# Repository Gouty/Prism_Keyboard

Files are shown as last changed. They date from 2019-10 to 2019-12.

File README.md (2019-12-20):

# Prism Pixel Art Prism Mechanical Keyboard

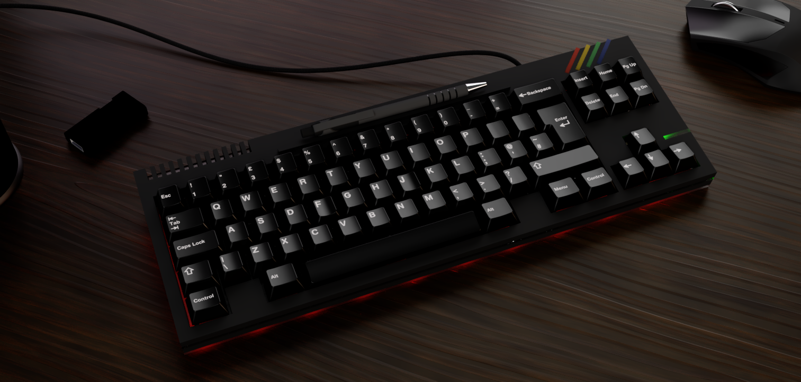
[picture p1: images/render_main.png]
Render


Prism is a low cost QMK compatable 60% + nav cluster (or TKL minus F-row if you prefer) keyboard.

It came about for a number of reasons:

 * I had some [TGW71 PCBs](https://www.reddit.com/r/MechanicalKeyboards/comments/5un33s/the_great_wave_custom_board/) designed by [u/ca178858](https://www.reddit.com/user/ca178858) lying around doing nothing
 * I am procrastinating instead of doing my PhD thesis writeup
 * There was a competition on [r/CustomKeyboards](https://www.reddit.com/r/CustomKeyboards/) to build retro themed keyboards.

As it was planned for the OG Summer competition I decided to emulate some of the design language of the [ZX Sepctrum](https://imgur.com/a/drfZssH) family of computers (particularly the the ones that came after the 48k).

## Initial Design document

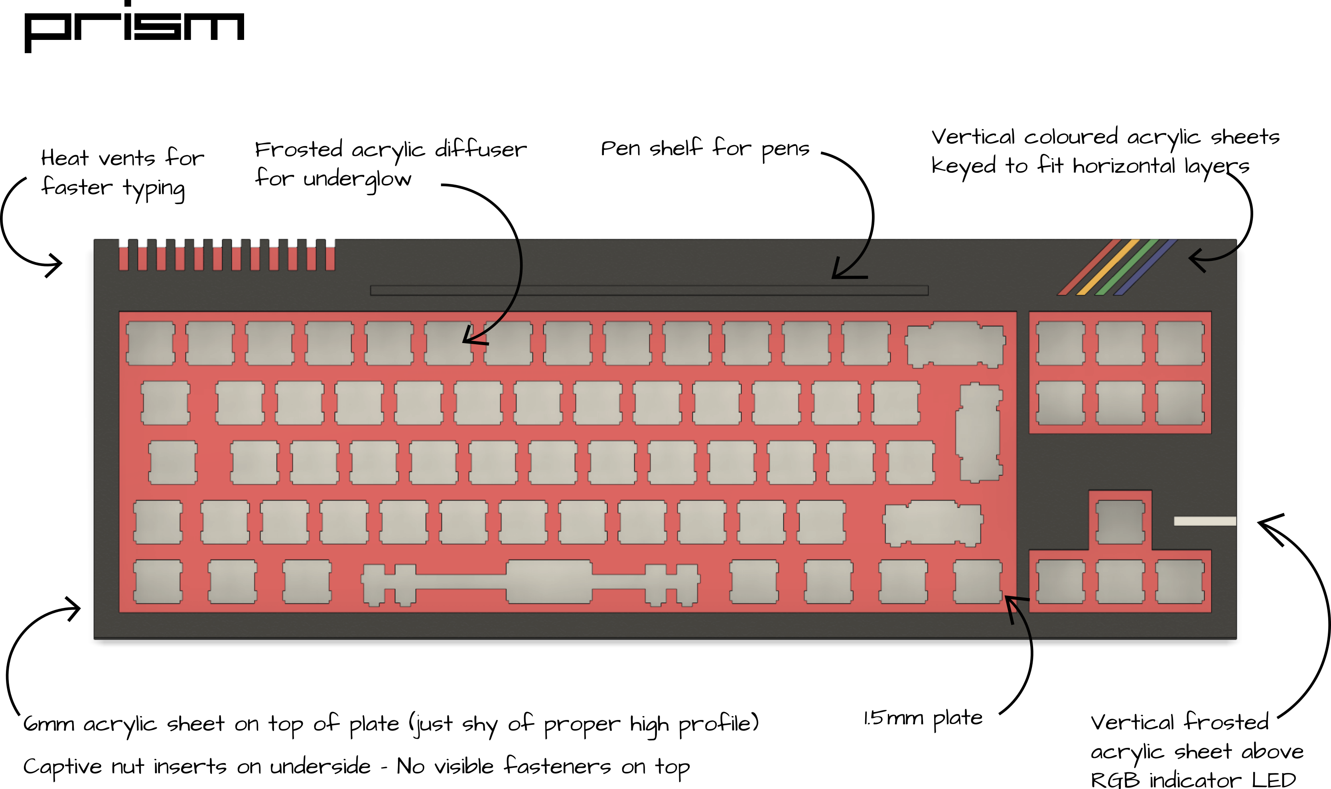
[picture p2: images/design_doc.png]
Design Doc
 explode

## To Do

* Improve feet fastening/height adjustment
* Update .dxf to include latest revision

## Future Plans

Currently this repo is a bit of a dumping ground for what I have designed so far, though it is possible to recreate the keyboard entirely. Eventually I want it to include:

* Multiple plate layer configurations
* Multiple top layer configuations
* Changes to the PCB to include PCB mount stabilisers and better bottom row support

## Current status

Prototype complete - Displayed at Mechanical Keyboard Meetup (Leeds 26/10/2019)

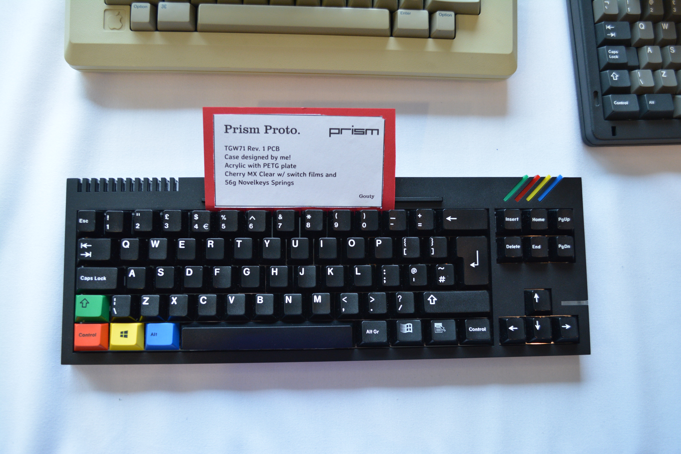
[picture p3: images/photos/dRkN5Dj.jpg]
MKUK Leeds


## Posts about Prism

* [Initial](https://www.reddit.com/r/CustomKeyboards/comments/c7dlp8/ogsummer_zx_spectrum_inspired_work_in_progress/)
* [Update](https://www.reddit.com/r/CustomKeyboards/comments/cu45r6/ogsummer_prism_zx_spectrum_inspired_update/)
* [Keebtalk](https://www.keebtalk.com/t/prism-a-zx-spectrum-inspired-low-cost-acrylic-case/)
* [Prototype](https://www.reddit.com/r/MechanicalKeyboards/comments/dqqovr/rbgy/), [2](https://www.reddit.com/r/CustomKeyboards/comments/dqr5ce/prism_prototype/)

## Thanks

Original TGW71 PCB by [u/ca178858](https://www.reddit.com/user/ca178858) and [u/the_pokemon_kid](https://www.reddit.com/user/the_pokemon_kid)

Pixel art by Meowsaur

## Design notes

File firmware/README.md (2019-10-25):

Trying to get buildfiles (if I don't get them I'll try and make my own) but in the meantime

.json works in [Keyboard Firmware Builder](https://kbfirmware.com/) but RGB doesn't work for some reason.

.hex currently uploaded works with basic layout and working RGB

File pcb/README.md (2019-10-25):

# TGW71 PCB

Original files kindly provided by [u/ca178858](https://www.reddit.com/user/ca178858)

BOM:

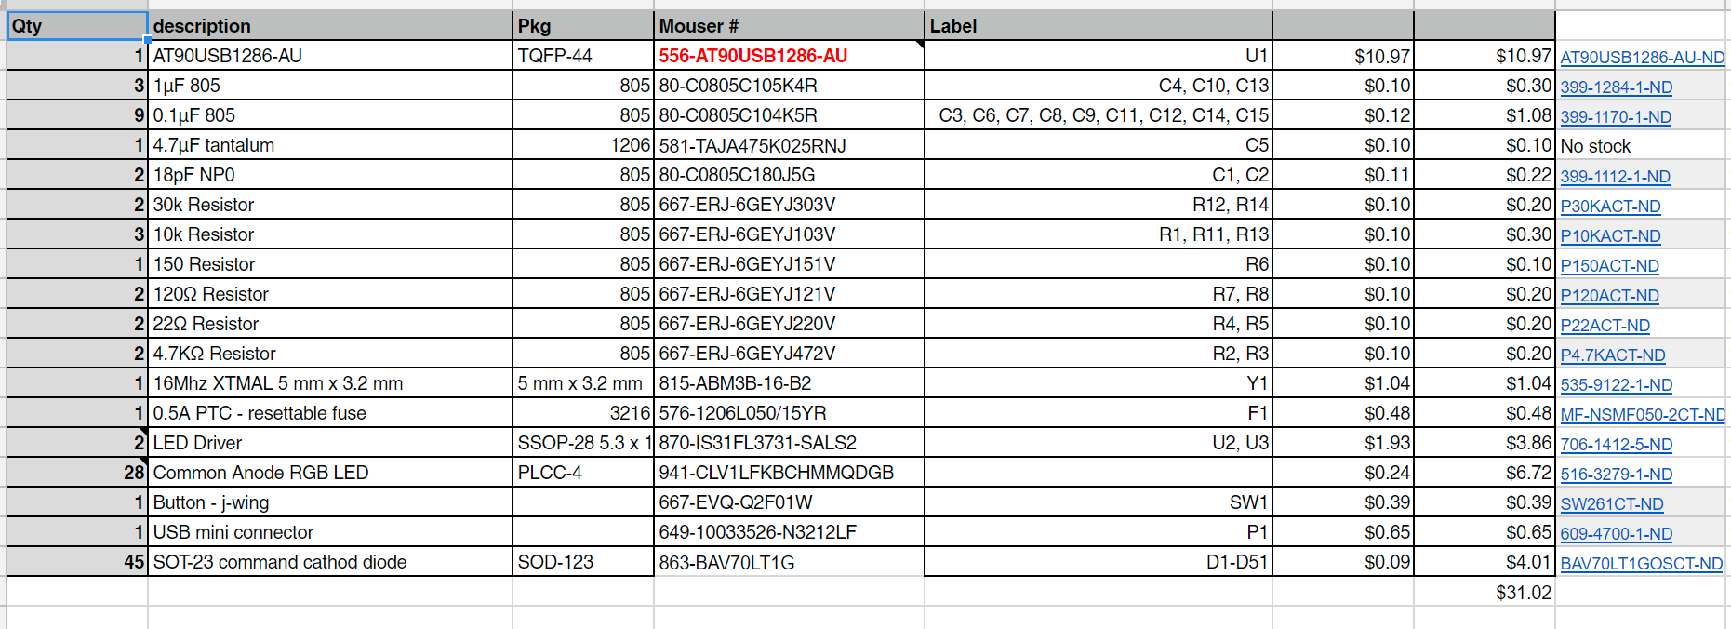
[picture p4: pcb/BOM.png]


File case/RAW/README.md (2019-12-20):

##Raw DXF files

The are the files organised into individual components.

They have no kerf applied to them, but slotted components do have additional small amount of clearance around them (0.15mm to 0.25mm)

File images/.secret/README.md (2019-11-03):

# Super Secret Cheeki Breeki Edition

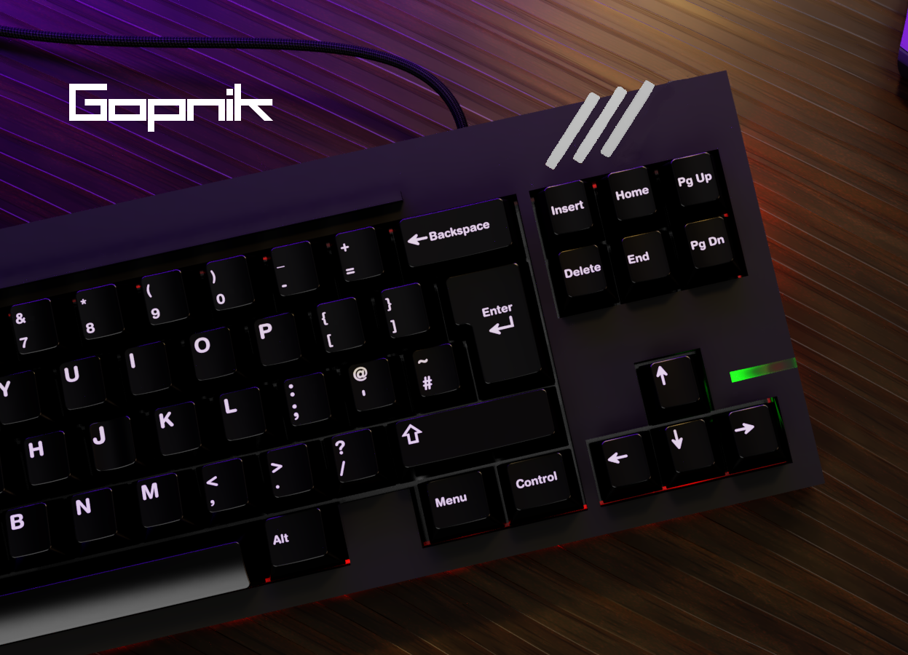
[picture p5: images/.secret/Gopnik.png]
Gopnik


No feet, flat squat on table just as mother ~~russia~~ nature intend.

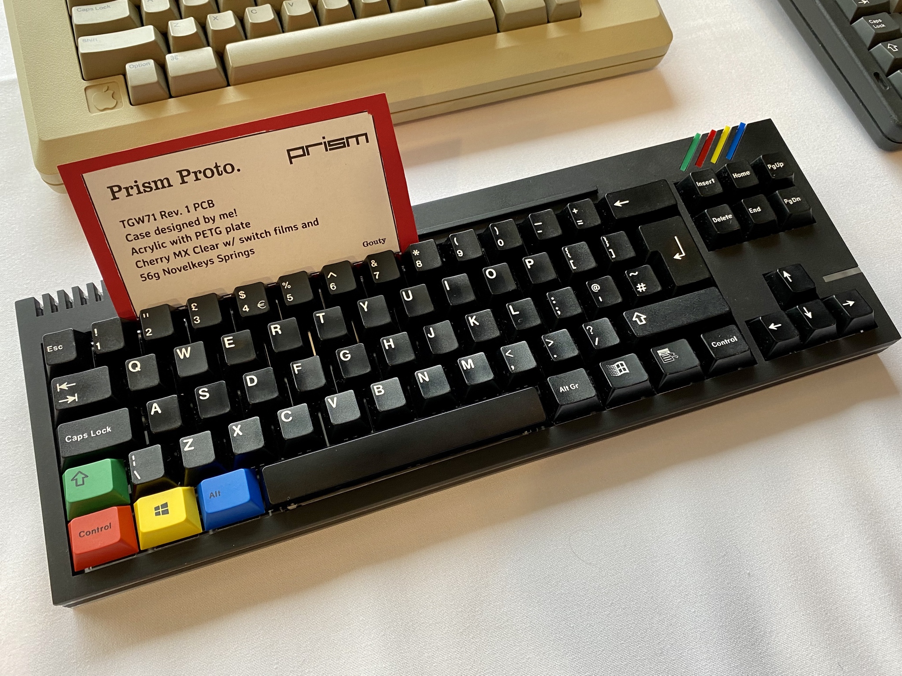
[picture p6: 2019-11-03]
images/photos/1HwlqcJ.jpg

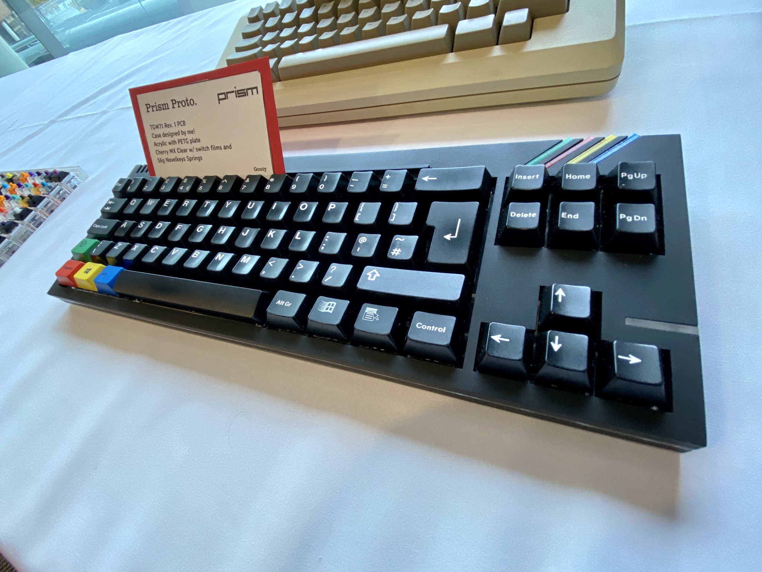
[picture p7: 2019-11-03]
images/photos/UL6nE1i.jpg

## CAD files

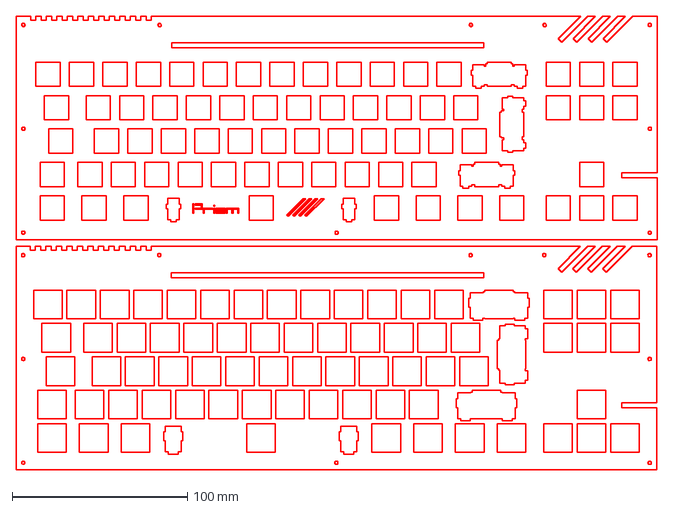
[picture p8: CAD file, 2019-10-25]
case/By material/Clear PETG 1_5mm.dxf
365.4 x 258.7 mm

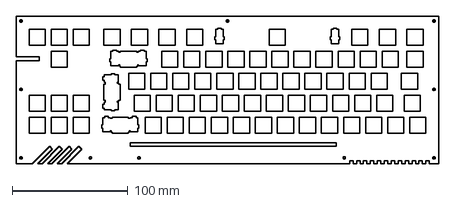
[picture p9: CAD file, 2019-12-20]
case/RAW/Plate(ISO).dxf
365.1 x 127.4 mm

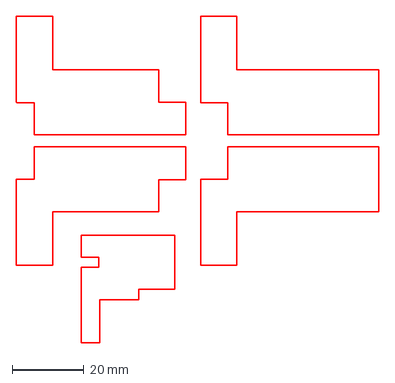
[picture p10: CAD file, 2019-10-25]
case/By material/Colours 3mm.dxf
101.2 x 91.3 mm

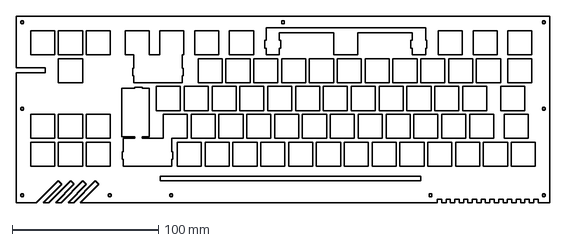
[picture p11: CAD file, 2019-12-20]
case/RAW/Underplate(ISO).dxf
365.1 x 127.4 mm

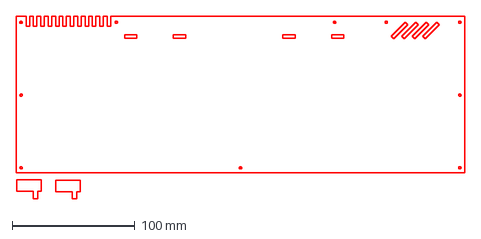
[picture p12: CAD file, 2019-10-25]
case/By material/Frosted Clear 3mm.dxf
365.3 x 148.7 mm

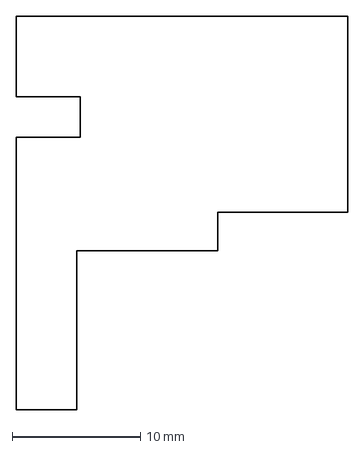
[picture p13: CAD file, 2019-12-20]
case/RAW/Colour Stripe.dxf
25.9 x 30.7 mm

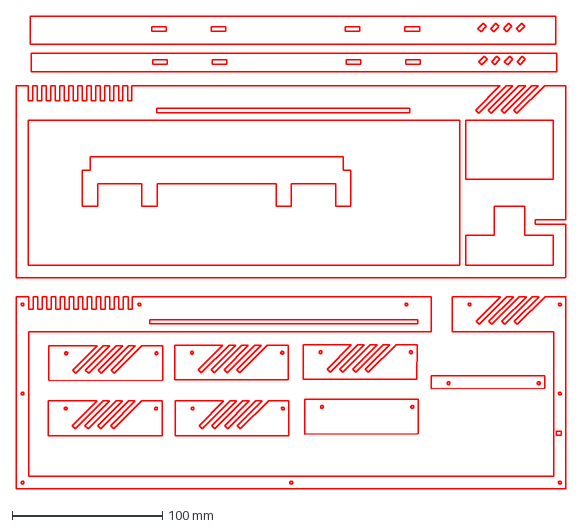
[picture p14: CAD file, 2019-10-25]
case/By material/Black 6mm.dxf
365.6 x 314.1 mm

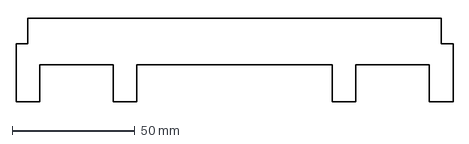
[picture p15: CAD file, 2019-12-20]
case/RAW/Pen holder.dxf
177.9 x 34.2 mm

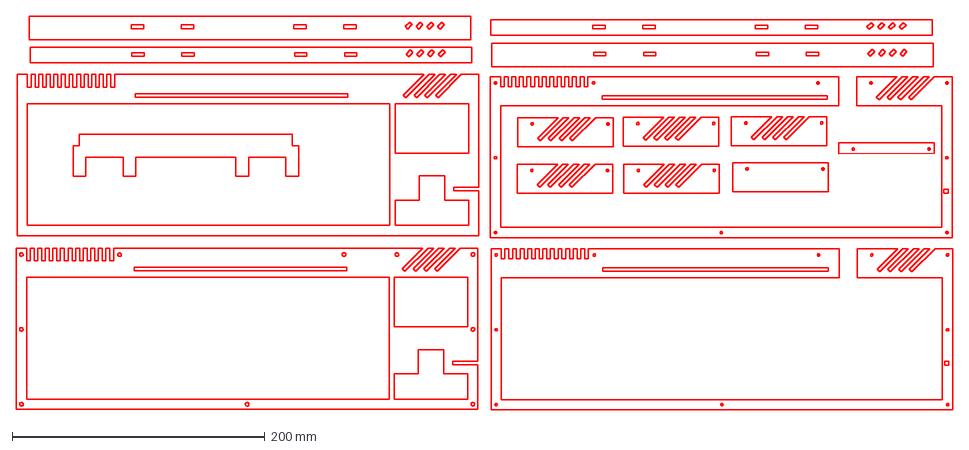
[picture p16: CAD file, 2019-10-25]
case/By material/Black 3mm.dxf
740.9 x 311.4 mm

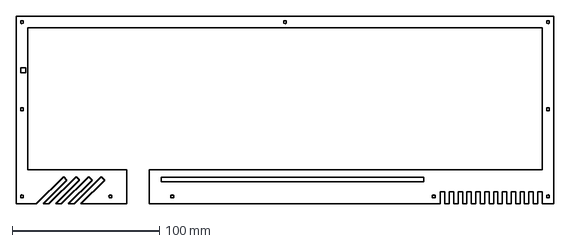
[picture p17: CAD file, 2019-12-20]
case/RAW/Mid.dxf
365.1 x 127.4 mm

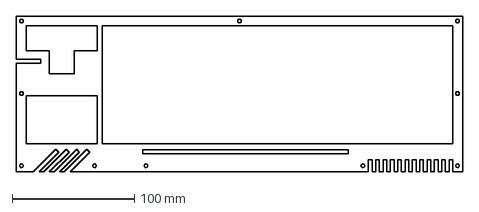
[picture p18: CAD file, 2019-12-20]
case/RAW/Top under.dxf
365.1 x 127.4 mm

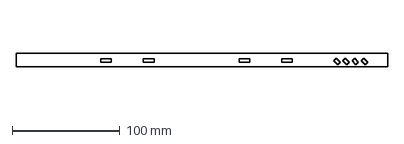
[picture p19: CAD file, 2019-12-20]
case/RAW/Bottom foot.dxf
345.1 x 12.3 mm

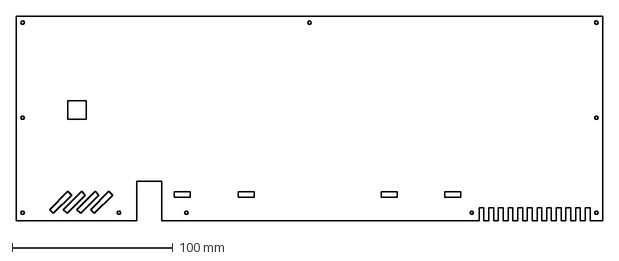
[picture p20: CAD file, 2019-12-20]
case/RAW/Base.dxf
365.1 x 127.4 mm

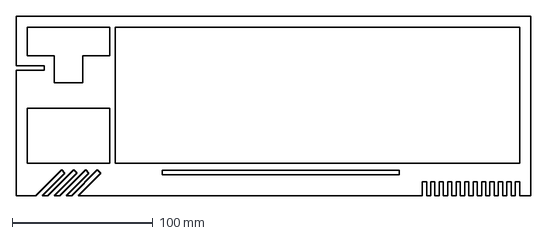
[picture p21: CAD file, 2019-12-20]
case/RAW/Top.dxf
365.1 x 127.4 mm

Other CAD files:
case/RAW/Colour Holder outer.dxf
case/RAW/Colour Holder inner.dxf
case/RAW/Top foot.dxf
case/RAW/Light Pipe.dxf

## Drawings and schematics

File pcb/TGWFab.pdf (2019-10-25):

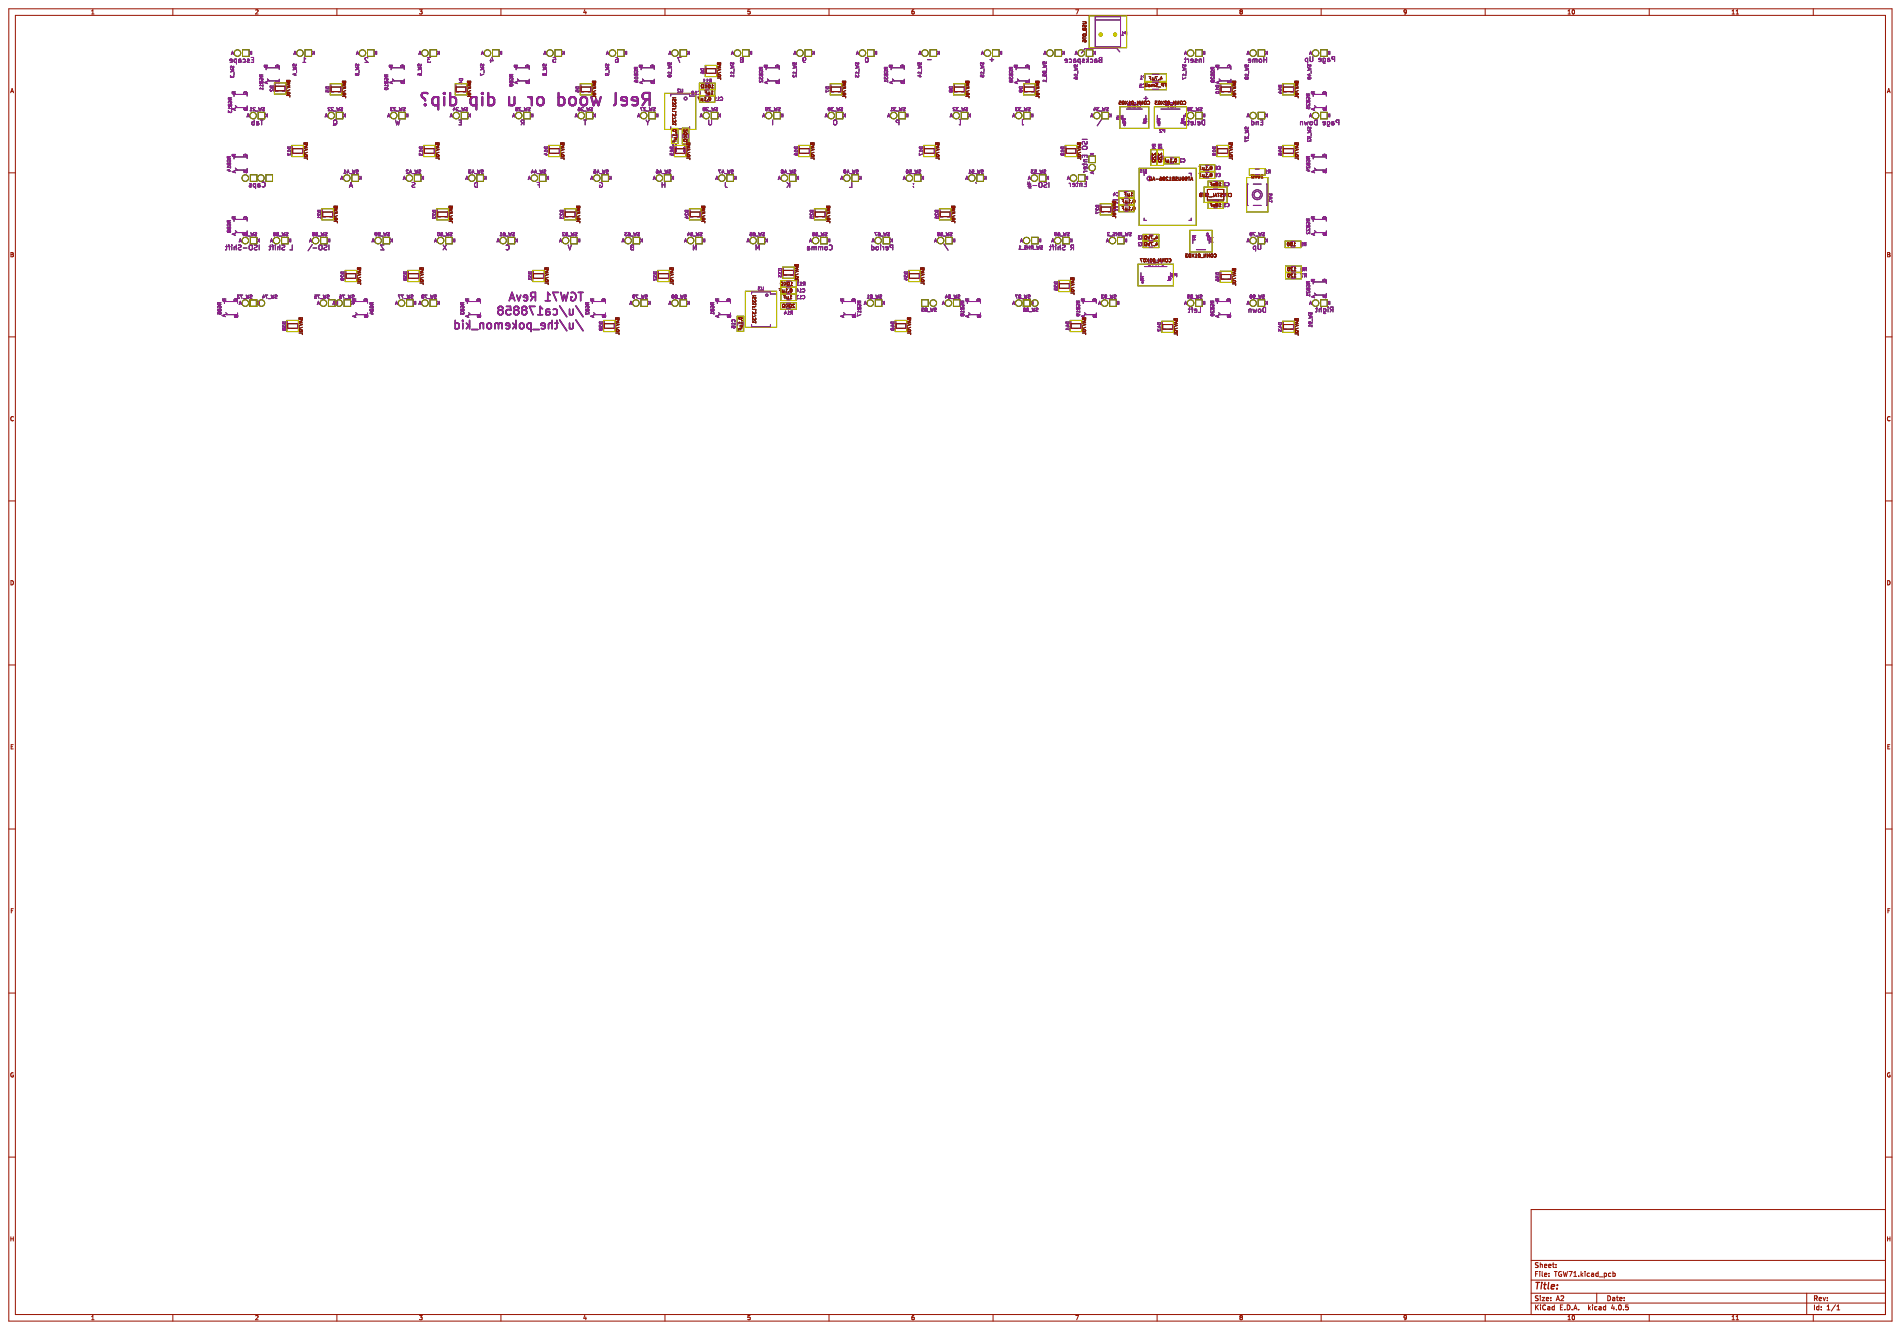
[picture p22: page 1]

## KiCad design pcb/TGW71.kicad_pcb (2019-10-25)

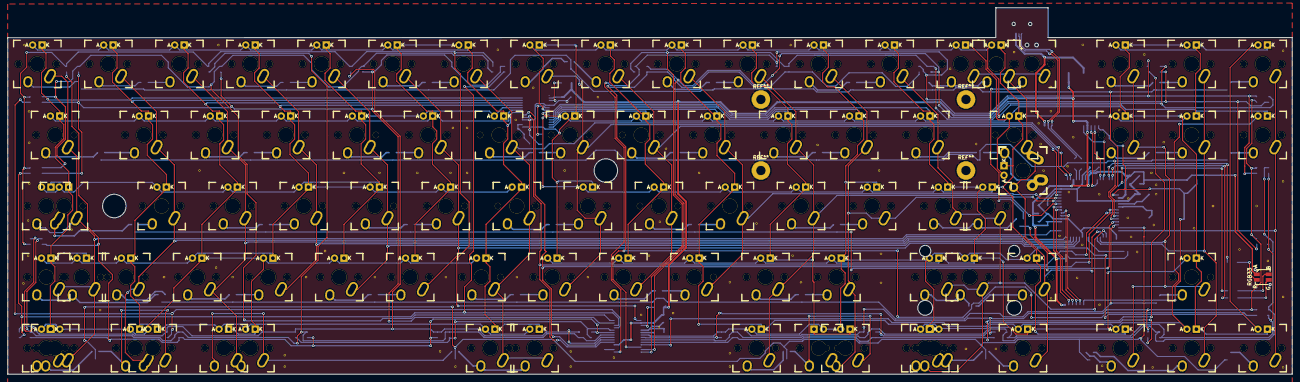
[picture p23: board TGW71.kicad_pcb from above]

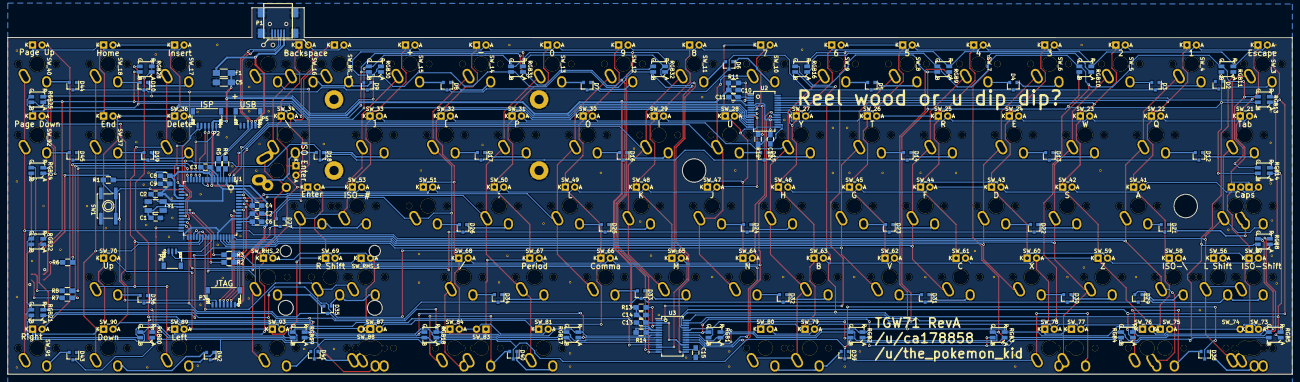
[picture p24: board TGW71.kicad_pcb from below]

Board: 2 copper layers, 344.5 x 98.3 mm, 192 parts (102 on the bottom side), 164 nets.

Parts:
C1, C2: 18pF; C_0805_HandSoldering
C3, C6, C7, C8, C9, C11, C12, C14, C15: 0.1µF; C_0805_HandSoldering
C4, C10, C13: 1µF; C_0805_HandSoldering
C5: 4.7µF; C_1206_HandSoldering
D2, D3, D4, D5, D6, D7, D8, D9, D10, D12, D13, D14, D15, D16, D17, D18, D19, D21, D22, D23, D24, D25, D26, D27, D29, D30, D31, D32, D33, D34, D35, D36, D38, D39, D40, D41, D42, D43, D44, D45: BAV70L; SOT-23
F1: FP_Small; C_1206_HandSoldering
P1: USB_OTG; USB_Mini-B
P2: CONN_02X03; JST_SH_SM06B-SRSS-TB_06x1.00mm_Angled
P3: CONN_01X07; JST_SH_SM07B-SRSS-TB_07x1.00mm_Angled
P4: CONN_01X03; JST_SH_SM03B-SRSS-TB_03x1.00mm_Angled
P5: CONN_01X05; JST_SH_SM05B-SRSS-TB_05x1.00mm_Angled
R1: 10kΩ; R_0805_HandSoldering
R2, R3: 4.7kΩ; R_0805_HandSoldering
R4, R5: 22Ω; R_0805_HandSoldering
R6: 150; R_0805_HandSoldering
R7, R8: 120; R_0805_HandSoldering
R11, R13: 10KΩ; R_0805_HandSoldering
R12, R14: 20KΩ; R_0805_HandSoldering
RGB1, RGB2, RGB3, RGB4, RGB5, RGB8, RGB9, RGB10, RGB11, RGB13, RGB14, RGB16, RGB17, RGB18, RGB19, RGB20, RGB21, RGB22, RGB24, RGB25, RGB28, RGB30, RGB31, RGB32: Led_RGB_CA; SMP4-RGB
RGB33: Led_RGB_CA; SMP4-RGB-PIPE
STA: Stabilizer; CHERRY_PCB_200_STABILIZER_OUTLINE
STA#2: Stabilizer; CHERRY_PCB_200_STABILIZER
SW1: SW_PUSH; SW_SPST_EVQP0
SW_3, SW_4, SW_5, SW_6, SW_7, SW_8, SW_9, SW_10, SW_11, SW_12, SW_13, SW_14, SW_15, SW_16, SW_17, SW_18, SW_21, SW_22, SW_23, SW_24, SW_25, SW_26, SW_27, SW_28, SW_29, SW_30, SW_31, SW_32, SW_33, SW_34, SW_35, SW_36, SW_37, SW_40, SW_41, SW_42, SW_43, SW_44, SW_45, SW_46, SW_47, SW_48, SW_49, SW_50, SW_51, SW_52, SW_53, SW_56, SW_57, SW_58, SW_59, SW_60, SW_61, SW_62, SW_63, SW_64, SW_65, SW_66, SW_67, SW_68, SW_69, SW_70, SW_73, SW_75, SW_76, SW_77, SW_78, SW_79, SW_80, SW_81, SW_84, SW_87, SW_89, SW_90, SW_91, SW_92, SW_93: MX_LED; MXALPS
SW_74, SW_83, SW_88: MX_LED; MXALPS_REVERSE_LED
SW_BS_1, SW_BS_2: MX_LED; MXALPS
SW_CAPS_1, SW_CAPS_2: MX_LED; MXALPS
SW_ISO_Alps_1: MX_LED; ALPS
SW_RHS_1, SW_RHS_2: MX_LED; MXALPS
U1: AT90USB1286-AU; TQFP-64_14x14mm_Pitch0.8mm
U2, U3: IS31FL3731; SSOP-28_5.3x10.2mm_Pitch0.65mm
Y1: CRYSTAL_SMD; Crystal_SMD_5032_4Pads

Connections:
+5V: C5.1, C6.1, C7.1, C8.1, C9.1, C10.1, C11.1, C13.1, C14.1, F1.2, P2.2, P3.1, P4.2, R1.1, R2.1, R3.1, R11.2, R13.2, RGB33.1, U1.3, U1.8, U1.21, U1.52, U1.64, U2.2, U3.2, U3.18
AUDIO: P4.3, U1.41
C3: SW_3.SW1, SW_21.SW1, SW_56.SW1, SW_57.SW1, SW_73.SW1, SW_74.SW1, SW_CAPS_1.SW2, SW_CAPS_2.SW1, U1.49
C4: SW_4.SW1, SW_22.SW1, SW_41.SW1, SW_58.SW1, SW_75.SW1, SW_76.SW2, U1.48
C5: SW_5.SW1, SW_23.SW1, SW_42.SW1, SW_59.SW1, SW_77.SW1, SW_78.SW2, U1.47
C6: SW_6.SW1, SW_24.SW1, SW_43.SW1, SW_60.SW1, U1.46
C7: SW_7.SW1, SW_25.SW1, SW_44.SW1, SW_61.SW1, U1.45
C8: SW_8.SW1, SW_26.SW1, SW_45.SW1, SW_62.SW1, U1.44
C9: SW_9.SW1, SW_27.SW1, SW_46.SW1, SW_63.SW1, SW_79.SW1, SW_80.SW1, U1.1
C10: SW_10.SW1, SW_28.SW1, SW_47.SW1, SW_64.SW1, U1.2
C11: SW_11.SW1, SW_29.SW1, SW_48.SW1, SW_65.SW1, U1.61
C12: SW_12.SW1, SW_30.SW1, SW_49.SW1, SW_66.SW1, U1.60
C13: SW_13.SW1, SW_31.SW1, SW_50.SW1, SW_67.SW1, SW_81.SW1, U1.59
C14: SW_14.SW1, SW_32.SW1, SW_51.SW1, SW_68.SW1, SW_83.SW1, SW_84.SW2, U1.58
C15: SW_15.SW1, SW_33.SW1, SW_52.SW1, SW_53.SW1, SW_69.SW1, SW_87.SW2, SW_88.SW2, SW_RHS_1.SW1, U1.35
C16: SW_16.SW1, SW_34.SW1, SW_35.SW1, SW_93.SW1, SW_BS_1.SW1, SW_BS_2.SW1, SW_ISO_Alps_1.SW2, SW_RHS_2.SW1, U1.36
C17: SW_17.SW1, SW_36.SW1, SW_70.SW1, SW_89.SW1, U1.37
C18: SW_18.SW1, SW_37.SW1, SW_90.SW1, U1.38
C19: SW_40.SW1, SW_91.SW1, SW_92.SW1, U1.32
D+: R5.1, U1.5
D-: R4.1, U1.4
GND: C1.2, C2.2, C3.2, C4.2, C5.2, C6.2, C7.2, C8.2, C9.2, C10.2, C11.2, C12.2, C13.2, C14.2, C15.2, P1.5, P1.6, P2.6, P3.7, P4.1, P5.5, R12.2, R14.2, SW1.1, U1.6, U1.22, U1.43, U1.53, U1.63, U2.5, U2.18, U3.5, Y1.3
LED_SCL: R2.2, U1.25, U2.20, U3.20
LED_SDA: R3.2, U1.26, U2.19, U3.19
L_CA1: SW_3.A, SW_4.A, SW_5.A, SW_6.A, SW_7.A, SW_8.A, SW_9.K, SW_27.K, SW_46.K, SW_63.K, SW_79.K, SW_80.K, U2.21
L_CA2: SW_8.K, SW_9.A, SW_21.A, SW_22.A, SW_23.A, SW_24.A, SW_25.A, SW_26.K, SW_45.K, SW_62.K, U2.22
L_CA3: SW_7.K, SW_25.K, SW_26.A, SW_27.A, SW_41.A, SW_42.A, SW_43.A, SW_44.K, SW_61.K, SW_CAPS_1.A, SW_CAPS_2.A, U2.23
L_CA4: SW_6.K, SW_24.K, SW_43.K, SW_44.A, SW_45.A, SW_46.A, SW_56.A, SW_57.A, SW_58.A, SW_59.A, SW_60.K, U2.24
L_CA5: SW_5.K, SW_23.K, SW_42.K, SW_59.K, SW_60.A, SW_61.A, SW_62.A, SW_63.A, SW_73.A, SW_74.A, SW_75.A, SW_76.A, SW_77.K, SW_78.K, U2.25
L_CA6: SW_4.K, SW_22.K, SW_41.K, SW_58.K, SW_75.K, SW_76.K, SW_77.A, SW_78.A, SW_79.A, SW_80.A, U2.26
L_CA7: SW_3.K, SW_21.K, SW_56.K, SW_57.K, SW_73.K, SW_74.K, SW_CAPS_1.K, SW_CAPS_2.K, U2.27
L_CB1: SW_10.A, SW_11.A, SW_12.A, SW_13.A, SW_14.A, SW_15.A, SW_16.A, SW_17.A, SW_18.K, SW_37.K, SW_40.K, SW_92.K, SW_BS_1.A, U2.7
L_CB2: SW_17.K, SW_18.A, SW_28.A, SW_29.A, SW_30.A, SW_31.A, SW_32.A, SW_33.A, SW_34.A, SW_35.A, SW_36.K, SW_70.K, SW_90.K, SW_91.K, SW_BS_1.K, U2.8
L_CB3: SW_16.K, SW_34.K, SW_35.K, SW_36.A, SW_37.A, SW_47.A, SW_48.A, SW_49.A, SW_50.A, SW_51.A, SW_52.K, SW_53.A, SW_89.K, SW_RHS_2.K, U2.9
L_CB4: SW_15.K, SW_33.K, SW_52.A, SW_53.K, SW_64.A, SW_65.A, SW_66.A, SW_67.A, SW_68.A, SW_69.K, SW_70.A, SW_93.K, SW_RHS_1.K, U2.10
L_CB5: SW_14.K, SW_32.K, SW_40.A, SW_51.K, SW_68.K, SW_69.A, SW_81.A, SW_83.A, SW_84.A, SW_87.K, SW_88.K, SW_91.A, SW_RHS_1.A, SW_RHS_2.A, U2.11
L_CB6: SW_13.K, SW_31.K, SW_50.K, SW_67.K, SW_83.K, SW_84.K, U2.12
L_CB7: SW_12.K, SW_30.K, SW_49.K, SW_66.K, SW_81.K, SW_87.A, SW_88.A, SW_89.A, SW_90.A, SW_92.A, SW_93.A, U2.13
L_CB8: SW_11.K, SW_29.K, SW_48.K, SW_65.K, U2.14
L_CB9: SW_10.K, SW_28.K, SW_47.K, SW_64.K, U2.15
MISO: P2.1, U1.13
MOSI: P2.4, U1.12
unnamed: C1.1, U1.24, Y1.1
unnamed: C2.1, U1.23, Y1.2
unnamed: C3.1, U1.7
unnamed: C4.1, U1.62
unnamed: C12.1, U2.16
unnamed: C15.1, U3.16
unnamed: D2.1, SW_3.SW2
unnamed: D3.1, SW_4.SW2
unnamed: D3.2, SW_5.SW2
unnamed: D4.1, SW_6.SW2
unnamed: D4.2, SW_7.SW2
unnamed: D5.1, SW_8.SW2
unnamed: D5.2, SW_9.SW2
unnamed: D6.1, SW_10.SW2
unnamed: D6.2, SW_11.SW2
unnamed: D7.1, SW_12.SW2
unnamed: D7.2, SW_13.SW2
unnamed: D8.1, SW_14.SW2
unnamed: D8.2, SW_15.SW2
unnamed: D9.1, SW_16.SW2, SW_BS_1.SW2
unnamed: D10.1, SW_17.SW2
unnamed: D10.2, SW_18.SW2
unnamed: D12.1, SW_21.SW2
unnamed: D12.2, SW_22.SW2
unnamed: D13.1, SW_23.SW2
unnamed: D13.2, SW_24.SW2
unnamed: D14.1, SW_25.SW2
unnamed: D14.2, SW_26.SW2
unnamed: D15.1, SW_27.SW2
unnamed: D15.2, SW_28.SW2
unnamed: D16.1, SW_29.SW2
unnamed: D16.2, SW_30.SW2
unnamed: D17.1, SW_31.SW2
unnamed: D17.2, SW_32.SW2
unnamed: D18.1, SW_33.SW2
unnamed: D18.2, SW_34.SW2, SW_35.SW2, SW_ISO_Alps_1.SW1
unnamed: D19.1, SW_36.SW2
unnamed: D19.2, SW_37.SW2
unnamed: D21.1, SW_CAPS_1.SW1, SW_CAPS_2.SW2
unnamed: D21.2, SW_41.SW2
unnamed: D22.1, SW_42.SW2
unnamed: D22.2, SW_43.SW2
unnamed: D23.1, SW_44.SW2
unnamed: D23.2, SW_45.SW2
unnamed: D24.1, SW_46.SW2
unnamed: D24.2, SW_47.SW2
unnamed: D25.1, SW_48.SW2
unnamed: D25.2, SW_49.SW2
unnamed: D26.1, SW_50.SW2
unnamed: D26.2, SW_51.SW2
unnamed: D27.1, SW_52.SW2, SW_53.SW2
unnamed: D27.2, SW_BS_2.SW2
unnamed: D29.1, SW_56.SW2, SW_57.SW2
unnamed: D29.2, SW_58.SW2
unnamed: D30.1, SW_59.SW2
unnamed: D30.2, SW_60.SW2
unnamed: D31.1, SW_61.SW2
unnamed: D31.2, SW_62.SW2
unnamed: D32.1, SW_63.SW2
unnamed: D32.2, SW_64.SW2
unnamed: D33.1, SW_65.SW2
unnamed: D33.2, SW_66.SW2
unnamed: D34.1, SW_67.SW2
unnamed: D34.2, SW_68.SW2
unnamed: D35.1, SW_69.SW2, SW_RHS_1.SW2
unnamed: D35.2, SW_RHS_2.SW2
unnamed: D36.2, SW_70.SW2
unnamed: D38.1, SW_73.SW2, SW_74.SW2
unnamed: D38.2, SW_75.SW2, SW_76.SW1
unnamed: D39.1, SW_77.SW2, SW_78.SW1
unnamed: D39.2, SW_79.SW2, SW_80.SW2
unnamed: D40.1, SW_81.SW2
unnamed: D40.2, SW_83.SW2, SW_84.SW1
unnamed: D41.1, SW_87.SW1, SW_88.SW1
unnamed: D41.2, SW_93.SW2
unnamed: D42.1, SW_89.SW2
unnamed: D42.2, SW_90.SW2
unnamed: D43.2, SW_91.SW2
unnamed: D44.2, SW_40.SW2
unnamed: D45.2, SW_92.SW2
unnamed: R6.1, RGB33.2
unnamed: R7.1, RGB33.3
unnamed: R8.1, RGB33.4
unnamed: R11.1, U2.3
unnamed: R12.1, U2.6
unnamed: R13.1, U3.3
unnamed: R14.1, U3.6
PWM_BLUE: R8.2, U1.17
PWM_GREEN: R7.2, U1.16
PWM_RED: R6.2, U1.15
R1: D2.3, D3.3, D4.3, D5.3, D6.3, D7.3, D8.3, D9.3, D10.3, D44.3, U1.27
R2: D12.3, D13.3, D14.3, D15.3, D16.3, D17.3, D18.3, D19.3, D45.3, U1.28
R3: D21.3, D22.3, D23.3, D24.3, D25.3, D26.3, D27.3, U1.29
R4: D29.3, D30.3, D31.3, D32.3, D33.3, D34.3, D35.3, D36.3, U1.30
R5: D38.3, D39.3, D40.3, D41.3, D42.3, D43.3, U1.31
RESET: P2.5, P3.6, R1.2, SW1.2, U1.20
R_CA1: RGB1.2, RGB2.2, RGB3.2, RGB4.2, RGB5.2, RGB8.2, RGB9.1, U3.21
R_CA2: RGB1.1, RGB2.3, RGB3.3, RGB4.3, RGB5.3, RGB8.3, RGB10.1, U3.22
R_CA3: RGB1.3, RGB2.1, RGB3.4, RGB4.4, RGB5.4, RGB8.4, RGB11.1, U3.23
R_CA4: RGB1.4, RGB2.4, RGB3.1, U3.24
R_CA5: RGB4.1, RGB13.1, U3.25
R_CA6: RGB5.1, RGB14.1, RGB16.4, U3.26
R_CA7: RGB9.4, RGB10.4, RGB11.4, RGB13.4, RGB14.4, RGB16.3, U3.27
R_CA8: RGB9.3, RGB10.3, RGB11.3, RGB13.3, RGB14.3, RGB16.1, U3.28
R_CA9: RGB8.1, RGB9.2, RGB10.2, RGB11.2, RGB13.2, RGB14.2, RGB16.2, U3.1
R_CB1: RGB17.2, RGB18.2, RGB19.2, RGB20.2, RGB21.2, RGB22.2, RGB24.2, RGB25.1, U3.7
R_CB2: RGB17.1, RGB18.3, RGB19.3, RGB20.3, RGB21.3, RGB22.3, RGB24.3, U3.8
R_CB3: RGB17.3, RGB18.1, RGB19.4, RGB20.4, RGB21.4, RGB22.4, RGB24.4, U3.9
R_CB4: RGB17.4, RGB18.4, RGB19.1, RGB28.1, U3.10
R_CB5: RGB20.1, U3.11
R_CB6: RGB21.1, RGB30.1, RGB31.4, RGB32.4, U3.12
R_CB7: RGB22.1, RGB25.4, RGB28.4, RGB30.4, RGB31.1, RGB32.3, U3.13
R_CB8: RGB25.3, RGB28.3, RGB30.3, RGB31.3, RGB32.1, U3.14
R_CB9: RGB24.1, RGB25.2, RGB28.2, RGB30.2, RGB31.2, RGB32.2, U3.15
SCK: P2.3, U1.11
TCK: P3.2, U1.57
TDI: P3.5, U1.54
TDO: P3.4, U1.55
TMS: P3.3, U1.56
USB+: P1.3, P5.3, R5.2
USB-: P1.2, P5.2, R4.2
VBUS: F1.1, P1.1, P5.1

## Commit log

2019-10-25 Added PCB Files
    [TGW71-B.Cu.gbl, TGW71-B.Mask.gbs, TGW71-B.SilkS.gbo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]
2019-10-25 Add case files
    v1 of case files, kerf applied is 0.15 (too tight on the vertical bits currently)
    [#Frosted Clear 3mm.dxf, Black 3mm.dxf, Black 6mm.dxf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]
2019-11-04 Removed broken .dxf, updated readme
    [#Frosted Clear 3mm.dxf]
2019-12-20 Changes to case and pixel art
    [Base.dxf, Black 3mm.dxf, Black 6mm.dxf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]
